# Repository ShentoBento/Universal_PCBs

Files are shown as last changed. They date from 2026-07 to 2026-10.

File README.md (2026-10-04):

# Universal PCBs
note: this was a draft written by AI, its got a ton of errors and is pending manual changes
**Open-source, QMK/VIA-compatible keyboard PCBs designed to fit as many cases as possible.**

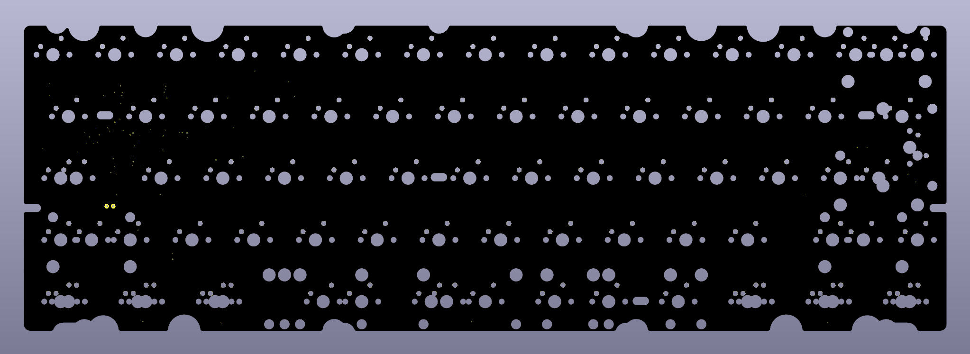
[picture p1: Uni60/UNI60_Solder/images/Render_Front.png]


Most custom keyboard cases are designed around one specific PCB. The boards in this repo work the other way around. Each one is built to drop into as many cases of its form factor as possible, by supporting a wide range of layouts and matching the connector and mounting positions that different cases expect.

---

## Boards

| Board | Form factor | Type | Status | Firmware |
|---|---|---|---|---|
| [**Uni60 Solder**](Uni60/UNI60_Solder) | 60% | Solder | Completed 50 unit GB, Sep 2026 | [Uni60/Solder](https://github.com/ShentoBento/Universal_PCBs_Firmware/tree/main/Uni60/Solder) |
| [**Uni60 Hotswap**](Uni60/UNI60_Hotswap) | 60% | Hotswap | In development | — |

Each board's folder has its own README with full specs, layout diagrams and ordering files.

---

## What "universal" means here

**Layouts.** Each board supports the common layout variations for its size. The Uni60 covers ANSI and ISO, split backspace, split left and right shift, stepped caps, and five bottom rows: 6.25u, 7u, 10u, 2.25u/1.25u/2.75u split, and 3u/1u/3u split.

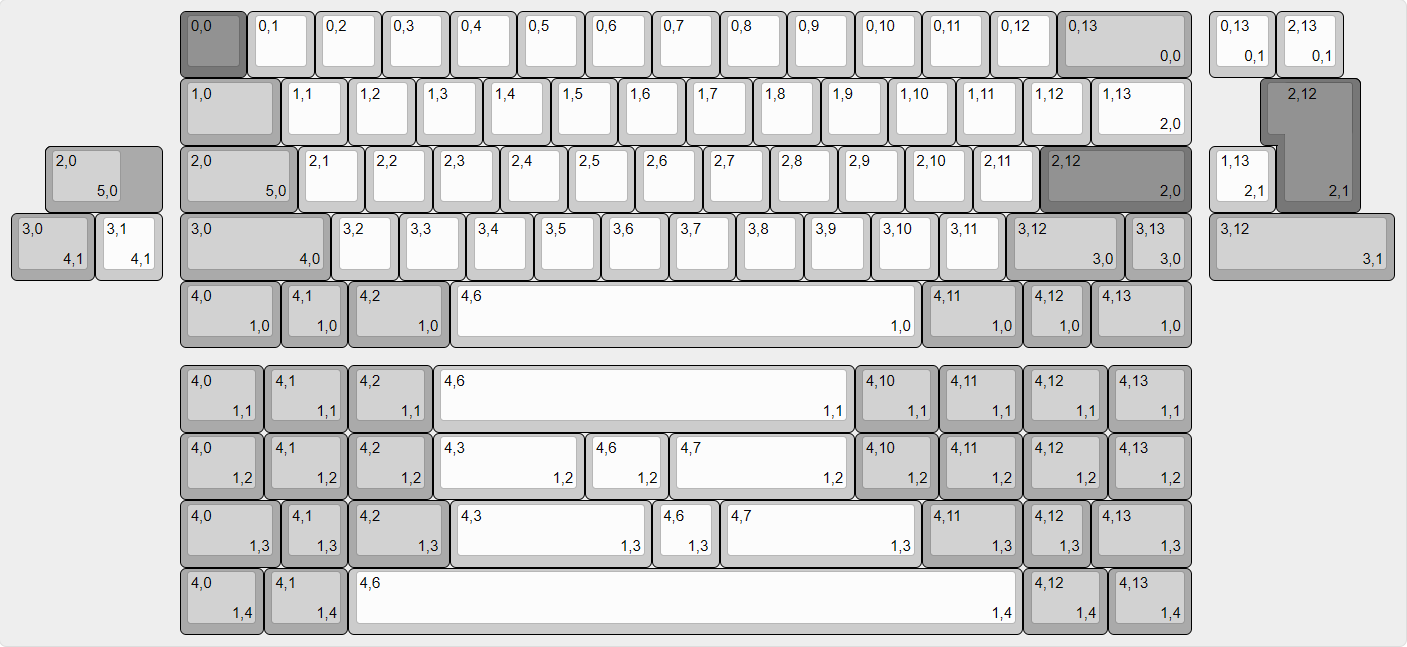
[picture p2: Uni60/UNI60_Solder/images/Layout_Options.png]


**Connectors.** Enthusiast cases route the USB daughterboard cable through a channel, and that channel sits in a different place in nearly every case. A tall JST-SH connector anywhere else bottoms out on the case floor. So the Uni60 has **five daisy-chained JST-SH positions** that line up with common channel locations. Keep the one your case uses and clip or desolder the rest. There's also a **Molex Pico-EZmate** connector, which sits lower than the switch pins and fits any case.

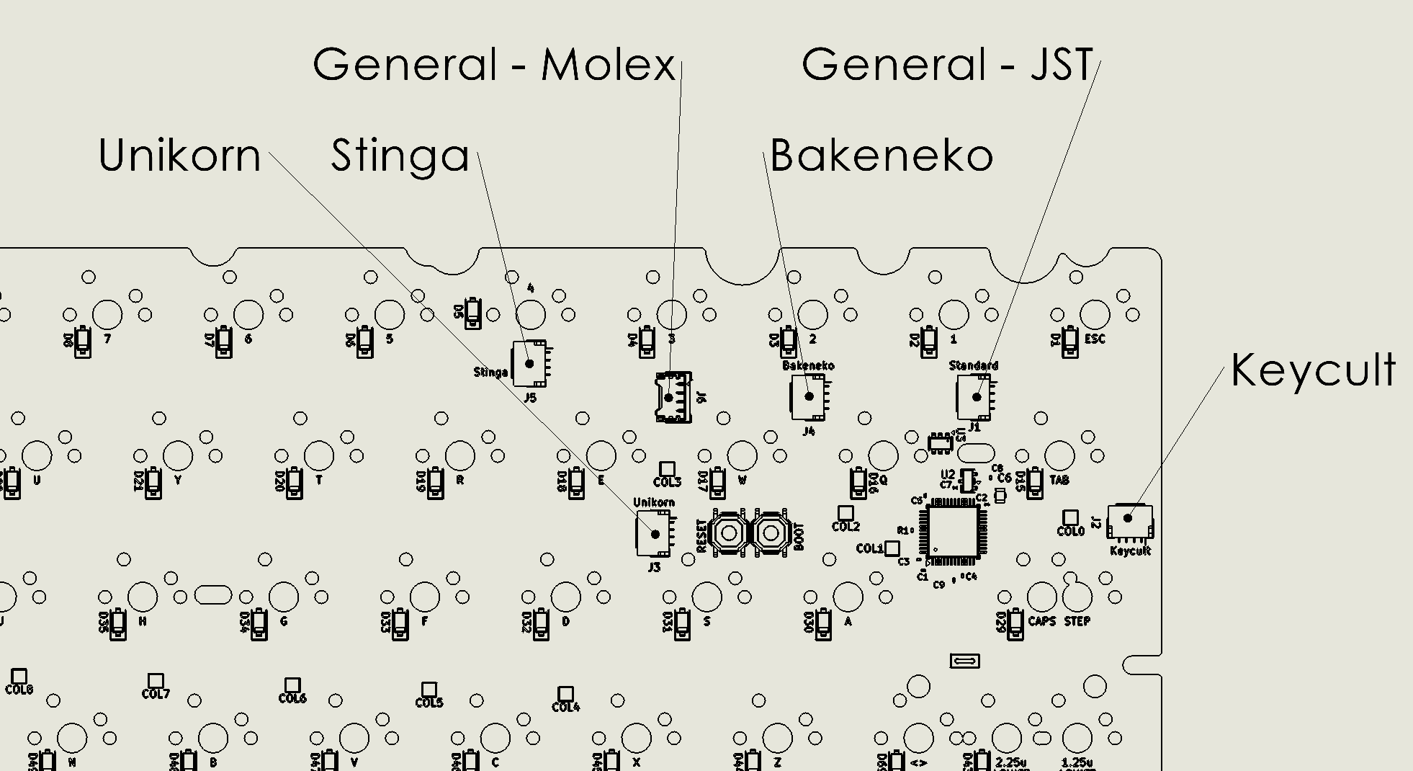
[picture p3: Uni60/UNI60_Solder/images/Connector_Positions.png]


**Outline and mounting.** The board outline is drawn to suit as many cases as possible. It includes tray-mount holes between keys, with the switch matrix routed around them.

---

## Shared specs

- **MCU:** STM32F072CBTx
- **Connectors:** JST-SH 4-pin (multiple positions) and Molex Pico-EZmate 4-pin
- **Firmware:** QMK with VIA and Vial support, in [Universal_PCBs_Firmware](https://github.com/ShentoBento/Universal_PCBs_Firmware)
- **Design tool:** KiCad 10 or newer (earlier versions won't open the files)
- **Manufacturing:** fab and assembly files generated for JLCPCB

---

## Repository layout

```
Universal_PCBs/
├── Uni60/
│   ├── UNI60_Solder/              complete: KiCad project, production files, images
│   └── UNI60_Hotswap/             in development
└── shentobento_kicad_library/     shared symbols, footprints and 3D models
```

## Using these files

1. Clone or download the **whole repo**, not just one board's folder. Every board points at the shared `shentobento_kicad_library/` with relative paths, so the projects open on any machine with no library setup.
2. Open the board's `.kicad_pro` file in KiCad 10 or newer.
3. To order boards, use the files in that board's `production/` folder (gerbers, BOM, positions). If you change the design, regenerate them with the JLCPCB Fabrication Toolkit plugin.

## Related

- [Universal_PCBs_Firmware](https://github.com/ShentoBento/Universal_PCBs_Firmware): QMK firmware for these boards
- [Velvet-Pro-Solder-PCB](https://github.com/ShentoBento/Velvet-Pro-Solder-PCB): the board whose matrix and MCU design the Uni60 builds on

## Credits and licenses

Keyboard footprints and symbols are derived from [marbastlib](https://github.com/ebastler/marbastlib) by ebastler, licensed under CERN-OHL-P v2. See `shentobento_kicad_library/LICENSE-marbastlib.txt`; modifications are logged in `shentobento_kicad_library/NOTICE.md`. Generic footprints come from the KiCad standard libraries.

---

Designed by **Andrew Shentu** ([@ShentoBento](https://github.com/ShentoBento)) · [LinkedIn](https://www.linkedin.com/in/andrewshentu)

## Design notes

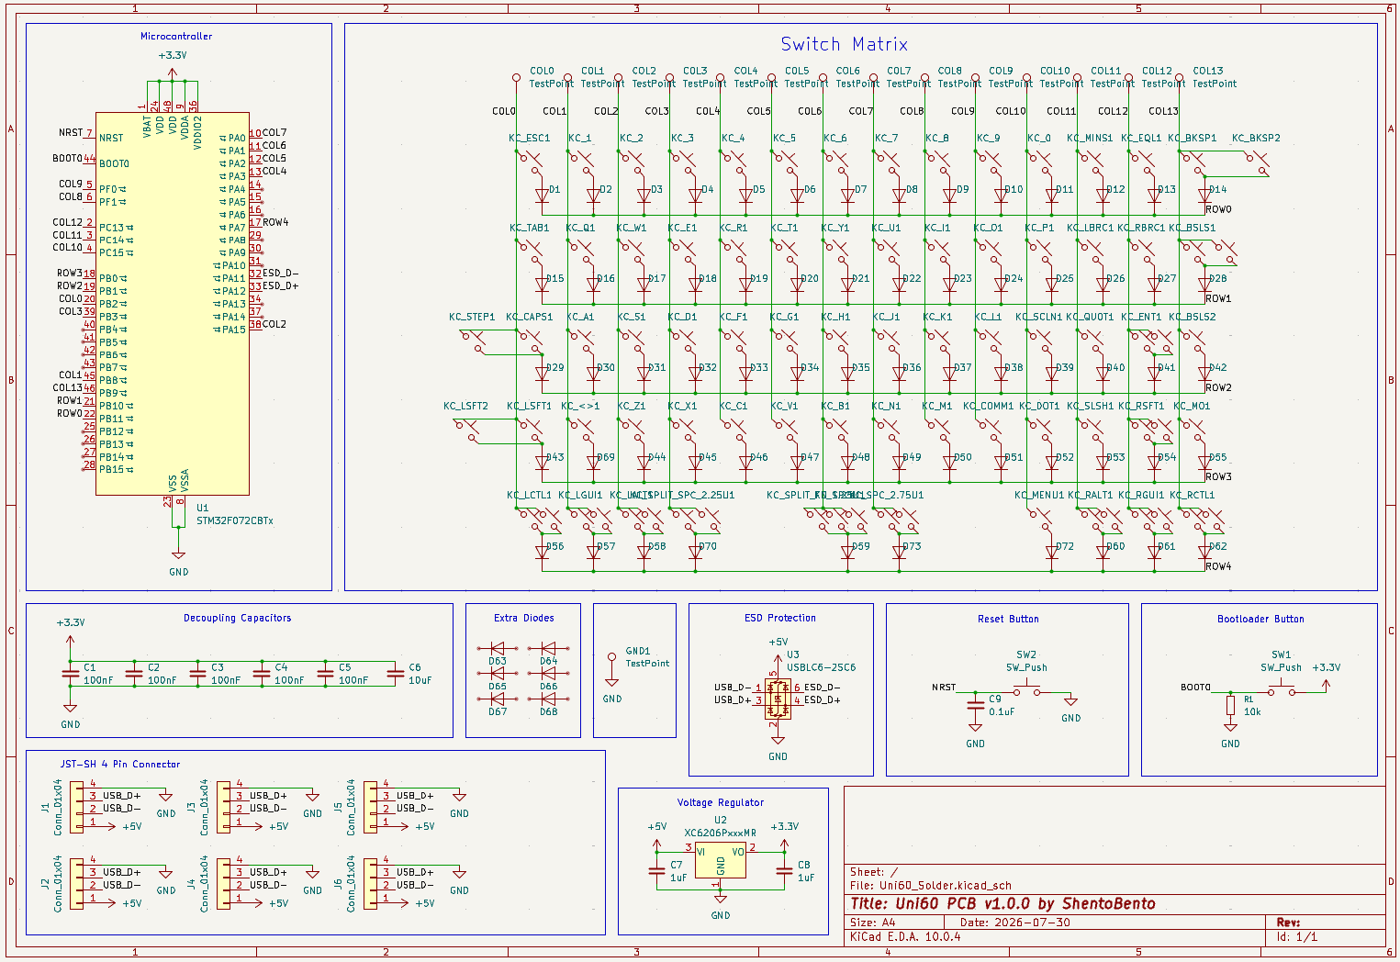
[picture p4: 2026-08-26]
Uni60/UNI60_Solder/images/Kicad_Schematic.png

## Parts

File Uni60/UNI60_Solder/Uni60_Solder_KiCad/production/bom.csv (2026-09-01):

Designator | Footprint | Quantity | Value | LCSC Part #
C1, C2, C3, C4, C5 | 0201 | 5 | 100nF
C6 | 0805 | 1 | 10uF
C7, C8 | 0201 | 2 | 1uF
C9 | 0201 | 1 | 0.1uF
COL0, COL1, COL10, COL11, COL12, COL13, COL2, COL3, COL4, COL5, COL6, COL7, COL8, COL9 | TestPoint_Pad_1.5x1.5mm | 14 | TestPoint
D1, D10, D11, D12, D13, D14, D15, D16, D17, D18, D19, D2, D20, D21, D22, D23, D24, D25, D26, D27, D28, D29, D3, D30, D31, D32, D33, D34, D35, D36, D37, D38, D39, D4, D40, D41, D42, D43, D44, D45, D46, D47, D48, D49, D5, D50, D51, D52, D53, D54, D55, D56, D57, D58, D59, D6, D60, D61, D62, D63, D64, D65, D66, D67, D68, D69, D7, D70, D72, D73, D8, D9 | D_SOD-123 | 72 | 1N4148
GND1 | TestPoint_Bridge_Pitch2.0mm_Drill0.7mm | 1 | TestPoint
J1, J2, J3, J4, J5 | JST_SH_1x04 | 5 | Conn_01x04
J6 | Molex_Pico-EZmate_78171-0004_1x04-1MP_P1.20mm_Vertical | 1 | Conn_01x04
KC_0, KC_1, KC_2, KC_3, KC_4, KC_5, KC_6, KC_7, KC_8, KC_9, KC_<>1, KC_A1, KC_B1, KC_BKSP1, KC_BKSP2, KC_BSLS2, KC_BSLS_ISO1, KC_C1, KC_COMM1, KC_D1, KC_DOT1, KC_E1, KC_ENT1, KC_ENT_ISO1, KC_EQL1, KC_ESC1, KC_F1, KC_G1, KC_H1, KC_I1, KC_J1, KC_K1, KC_L1, KC_LBRC1, KC_LGUI1, KC_LSFT1, KC_M1, KC_MINS1, KC_MO1, KC_N1, KC_O1, KC_P1, KC_Q1, KC_QUOT1, KC_R1, KC_RBRC1, KC_RGUI1, KC_RSFT1, KC_RSFT_2.75U1, KC_S1, KC_SCLN1, KC_SLSH1, KC_SPC1, KC_SPC_2.75U1, KC_SPC_3U1, KC_SPC_6.25U1, KC_SPLIT_SPC_2.25U1, KC_SPLIT_SPC_3U1, KC_T1, KC_U1, KC_V1, KC_W1, KC_X1, KC_Y1, KC_Z1 | SW_MX_1u | 65 | MX_SW_solder
KC_BSLS1, KC_LALT1, KC_LCTL1, KC_RALT1, KC_RCTL1, KC_TAB1 | SW_MX_1.5u | 6 | MX_SW_solder
KC_CAPS1 | SW_MX_1.75u | 1 | MX_SW_solder
KC_LALT_1.25U1, KC_LCTL_1.25U1, KC_LGUI_1.25U1, KC_LSFT2, KC_MENU1, KC_RALT_1.25U1, KC_RCTL_1.25U1, KC_RGUI_1.25U1, KC_SPLIT_FN_1.25U1 | SW_MX_1.25u | 9 | MX_SW_solder
KC_STEP1 | SW_MX_1.75u_STEPPED_1.25 | 1 | MX_SW_solder
R1 | 0201 | 1 | 10k
SW1, SW2 | SW_Push_Reset_Bootloader | 2 | SW_Push
U1 | MCU_STM32F072CBTx | 1 | STM32F072CBTx
U2 | SOT-23-3 | 1 | XC6206PxxxMR
U3 | SOT-23-6 | 1 | USBLC6-2SC6

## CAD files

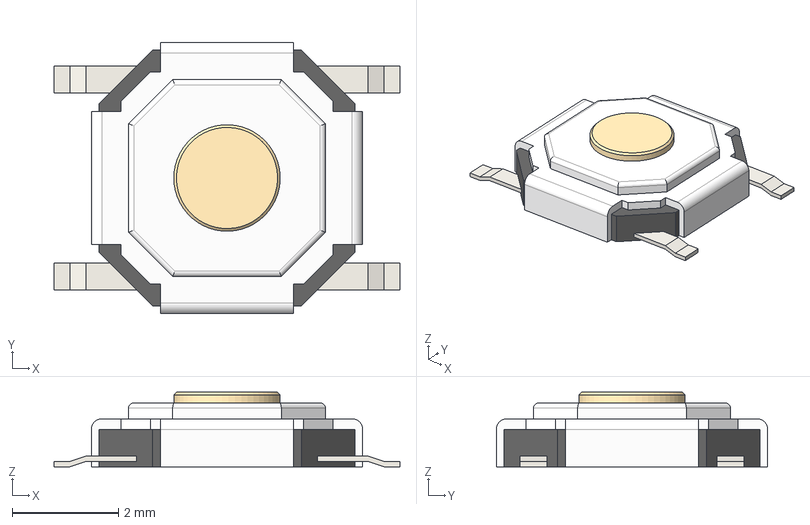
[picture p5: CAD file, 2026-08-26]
shentobento_kicad_library/3dmodels/TS-1187A.step
6.50 x 5.10 x 1.40 mm

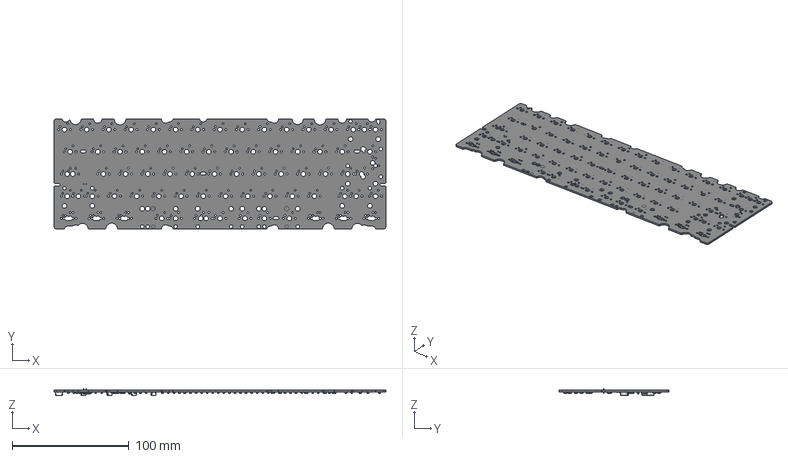
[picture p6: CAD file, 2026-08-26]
Uni60/UNI60_Solder/files/UNI60_PCB.step
284.7 x 94.2 x 5.96 mm
D_SOD-123 x 72
C_0201_0603Metric x 8
CON_781710004 v2
R_0201_0603Metric
TS-1187A v2 x 2
JST_SH_SM04B-SRSS-TB_1x04-1MP_P1.00mm_Horizontal x 5
SOT-23-6
LQFP-48_7x7mm_P0.5mm
TestPoint_Bridge_Pitch2.0mm_Drill0.7mm
C_0805_2012Metric
SOT-23-3
Uni60_Solder_silkscreen
Uni60_Solder_PCB

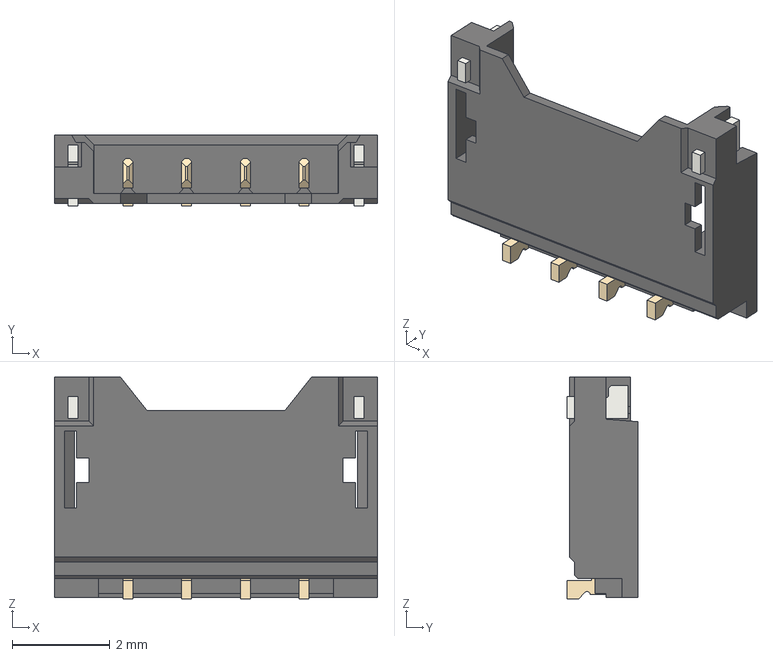
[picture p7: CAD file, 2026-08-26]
shentobento_kicad_library/3dmodels/CON_781710004.step
6.60 x 1.45 x 4.53 mm

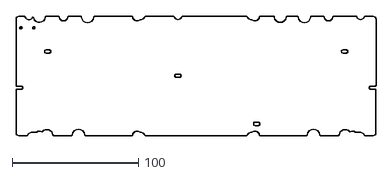
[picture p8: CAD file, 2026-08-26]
Uni60/UNI60_Solder/files/Uni60_PCB_Outline.dxf
284.7 x 94.2

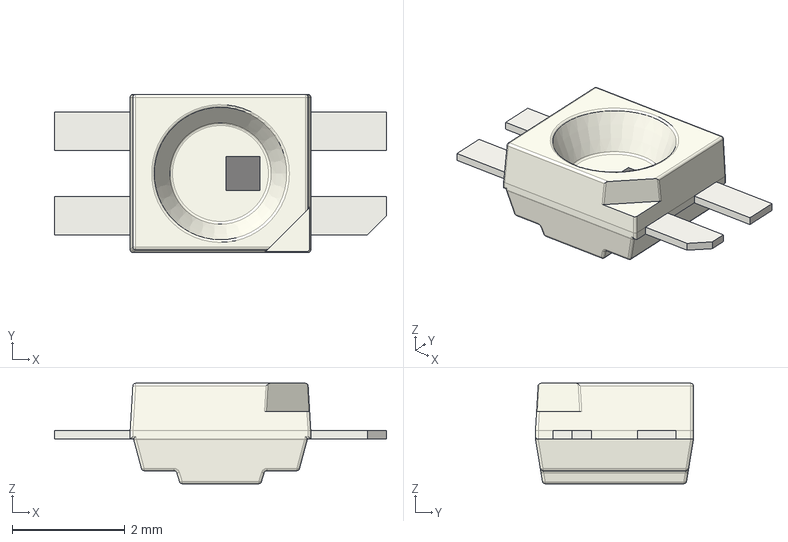
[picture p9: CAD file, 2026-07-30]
shentobento_kicad_library/3dmodels/LED_SK6812MINI-E.step
5.88 x 2.80 x 1.78 mm

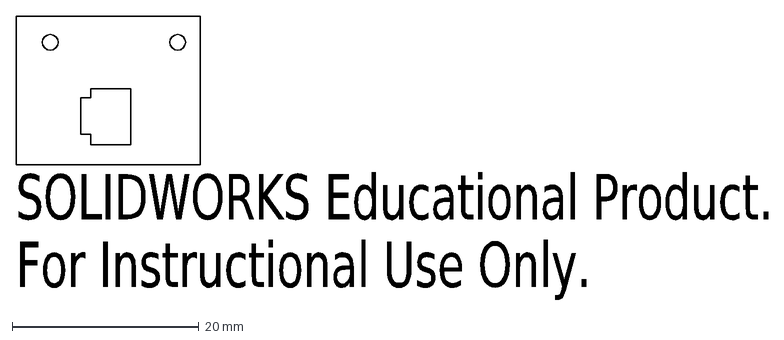
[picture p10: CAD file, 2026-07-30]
Uni60/UNI60_Solder/files/JST Position.DXF
SOLIDWORKS Educational Product.
For Instructional Use Only.

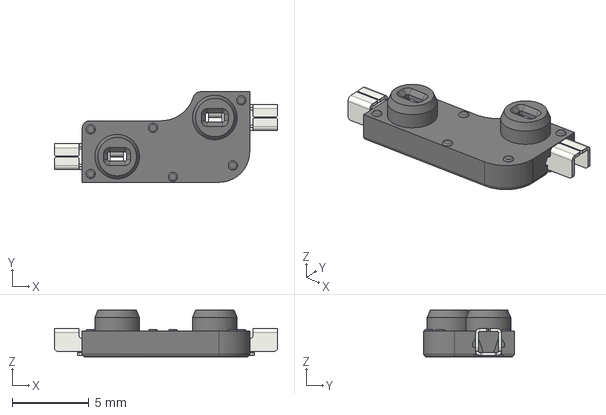
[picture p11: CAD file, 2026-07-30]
shentobento_kicad_library/3dmodels/HS_CPG151101S11_MX.step
14.5 x 5.89 x 3.05 mm
Contact x 2

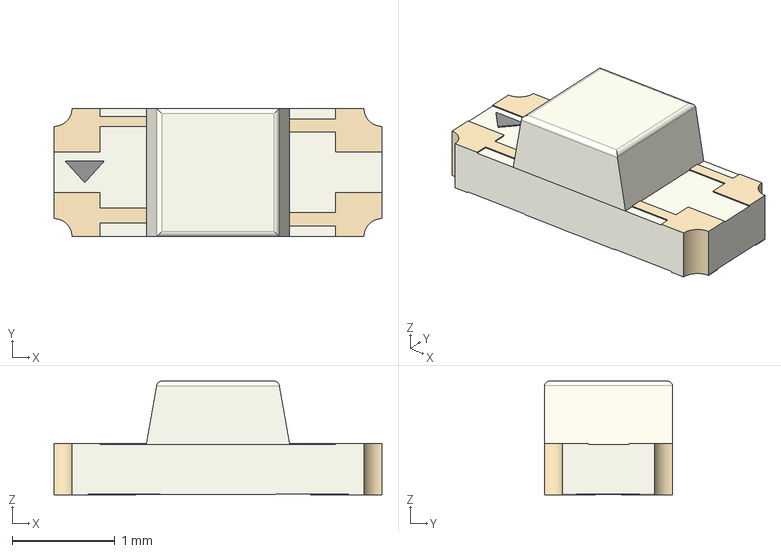
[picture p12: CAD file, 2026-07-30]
shentobento_kicad_library/3dmodels/LED_MHT151RGBCT.step
3.20 x 1.25 x 1.11 mm

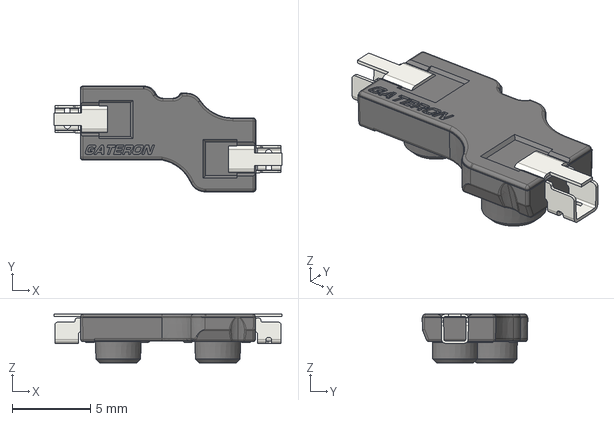
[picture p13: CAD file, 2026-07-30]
shentobento_kicad_library/3dmodels/HS_KS-2P02B01-01_MX.step
14.6 x 6.74 x 3.10 mm

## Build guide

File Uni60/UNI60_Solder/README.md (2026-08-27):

# Uni60 Solder PCB



A solder PCB designed to fit most JST-dependent 60% Keyboards.

Firmware: https://github.com/ShentoBento/Universal_PCBs_Firmware/tree/main/Uni60/Solder

---

## Specs



- Solder
- MCU: STM32F072CBTx
- 5 JST SH connector positions
- 1.55mm socket diameters (compatible with millmax)
- 1 molex pico ezmate connector
- ISO support
- Split backspace
- Split right shift
- Split left shift
- Stepped/full caps
- 7u/6.25u bottom row
- 2.25/1.25u/2.75u split spacebar
- 3u/1u/3u split spacebar
- 10u spacebar
- VIA and Vial compatible (via the firmware linked above)



---

## Requirements

- **KiCad 10** or newer. Earlier versions will not open these files.
- Nothing else. All symbols, footprints, and 3D models used by this project are
  included in this repo — no external libraries to install, no PCM packages,
  no library paths to configure.

---

## Opening the project

1. Clone or download this whole repo (not just the specific pcb folder).
2. Open `Uni60_Solder_KiCad/Uni60_Solder.KiCad_pro` in KiCad.

The library paths are stored relative to the project folder, so the repo works
from any location on any operating system. If KiCad reports missing symbols or
footprints, the most likely cause is that the `shentobento_kicad_library/`
folder was not cloned alongside.

---

## What's in this repo

### `Uni60_Solder_KiCad/`

The KiCad project. These are the files you edit.

| File | What it is |
|---|---|
| `Uni60_Solder.kicad_pro` | Project file — **open this one** |
| `Uni60_Solder.kicad_sch` | Schematic |
| `Uni60_Solder.kicad_pcb` | Board layout |
| `fp-lib-table`, `sym-lib-table` | Point KiCad at the bundled library |
| `fabrication-toolkit-options.json` | Settings for the JLCPCB fabrication plugin |

### `Uni60_Solder_KiCad/production/`

Ready-to-order manufacturing files, generated with the JLCPCB Fabrication Toolkit plugin.

| File | Upload it to |
|---|---|
| `Uni60_Solder.zip` | JLCPCB's gerber upload — this is the board itself |
| `bom.csv` | Assembly service (which parts) |
| `positions.csv` | Assembly service (where they go) |

If you modify the design, **regenerate these** with the JLCPCB Fabrication Toolkit plugin.

### `shentobento_kicad_library/`

Every symbol and footprint this project uses, in one place.

- `shentobento.kicad_sym` — all symbols
- `shentobento.pretty/` — all footprints
- `3dmodels/` — 3D models for the parts that need them

Symbols come with their footprints pre-assigned, so dragging a part into a
schematic gives you a working part with no footprint assignment step.

This folder is self-contained and can be copied into other keyboard projects.

### `files and images`

- `Uni60_PCB_Outline.dxf` — outline used for the pcb
- `JST Position.dxf` — the General-JST connector position

---

## Credits and licenses

Keyboard footprints and symbols are derived from
[marbastlib](https://github.com/ebastler/marbastlib) by ebastler, licensed under
CERN-OHL-P v2. See `shentobento_kicad_library/LICENSE-marbastlib.txt`.

Generic footprints (passives, SOT-23, LQFP-48, JST SH, test points) are copied
from the KiCad standard libraries.

Modifications made to third-party files are recorded in
`shentobento_kicad_library/NOTICE.md`.

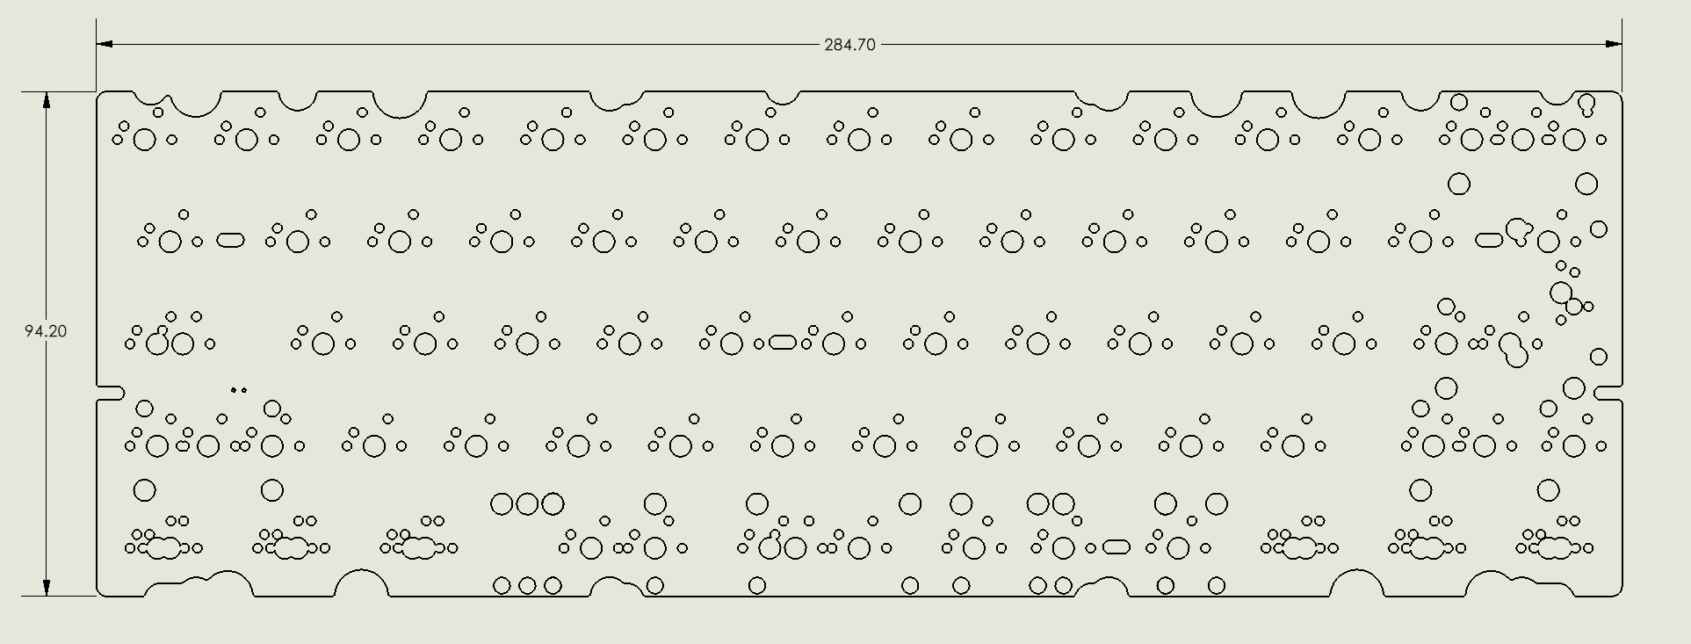
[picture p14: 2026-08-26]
Uni60/UNI60_Solder/images/Dimensions.png

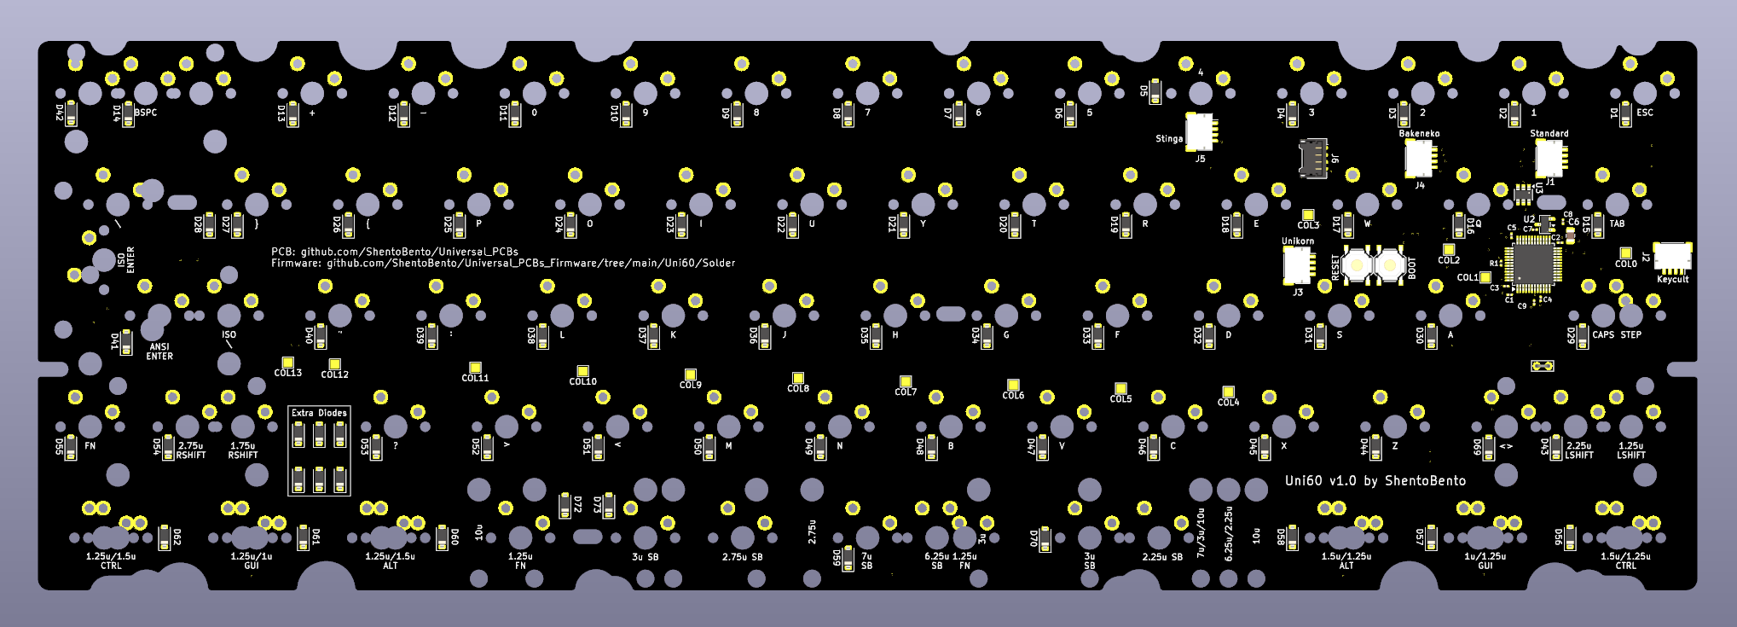
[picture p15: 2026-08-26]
Uni60/UNI60_Solder/images/Render_Back.png

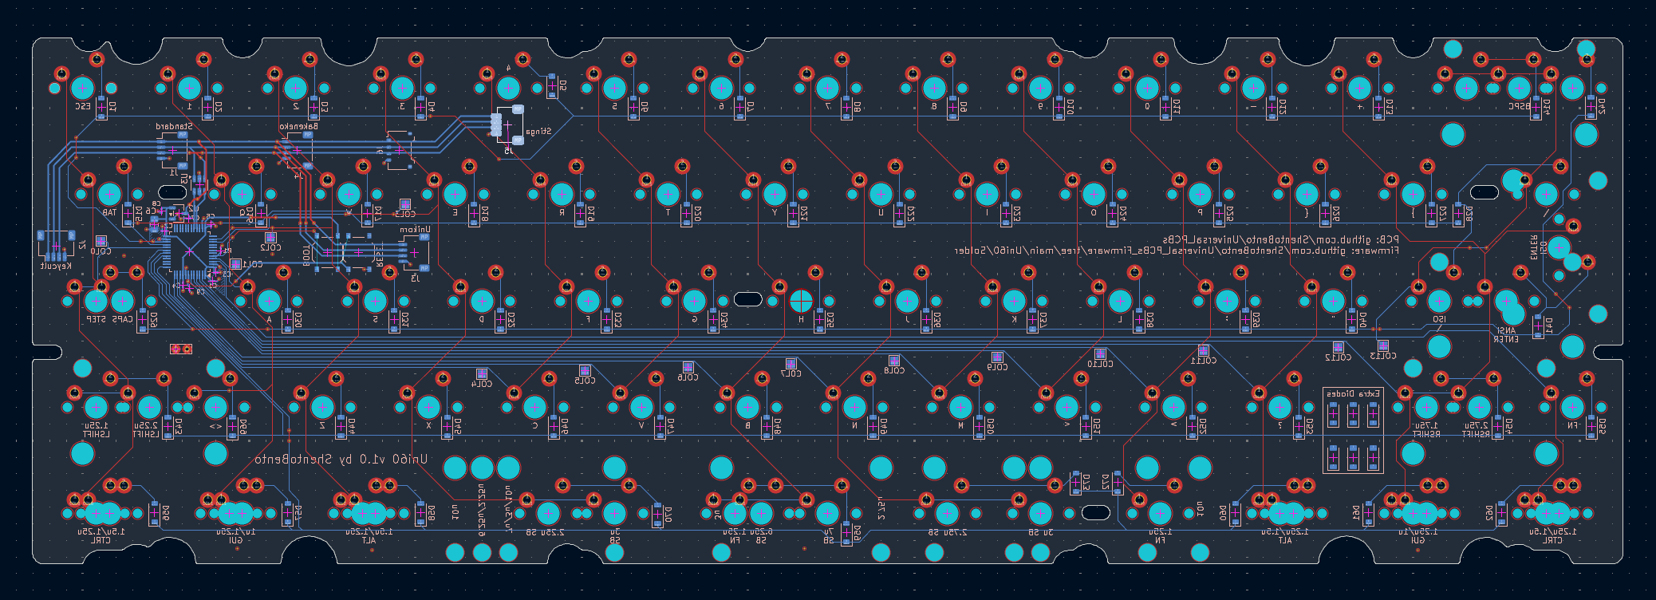
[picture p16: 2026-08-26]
Uni60/UNI60_Solder/images/Kicad_PCB.png

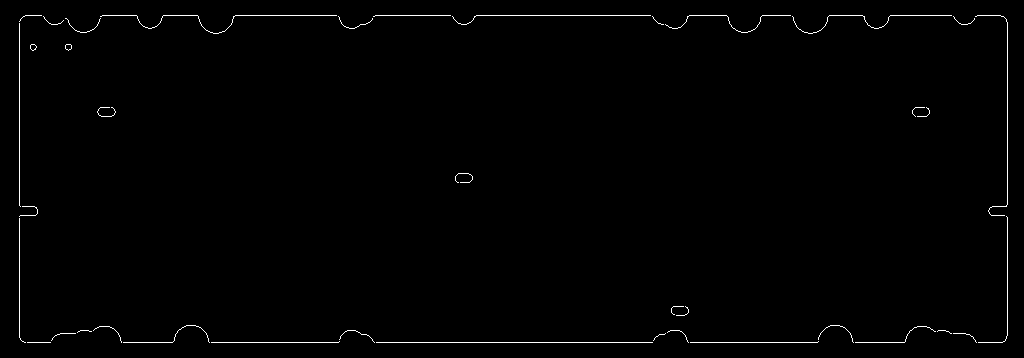
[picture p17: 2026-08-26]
Uni60/UNI60_Solder/files/Uni60_PCB_Outline.png

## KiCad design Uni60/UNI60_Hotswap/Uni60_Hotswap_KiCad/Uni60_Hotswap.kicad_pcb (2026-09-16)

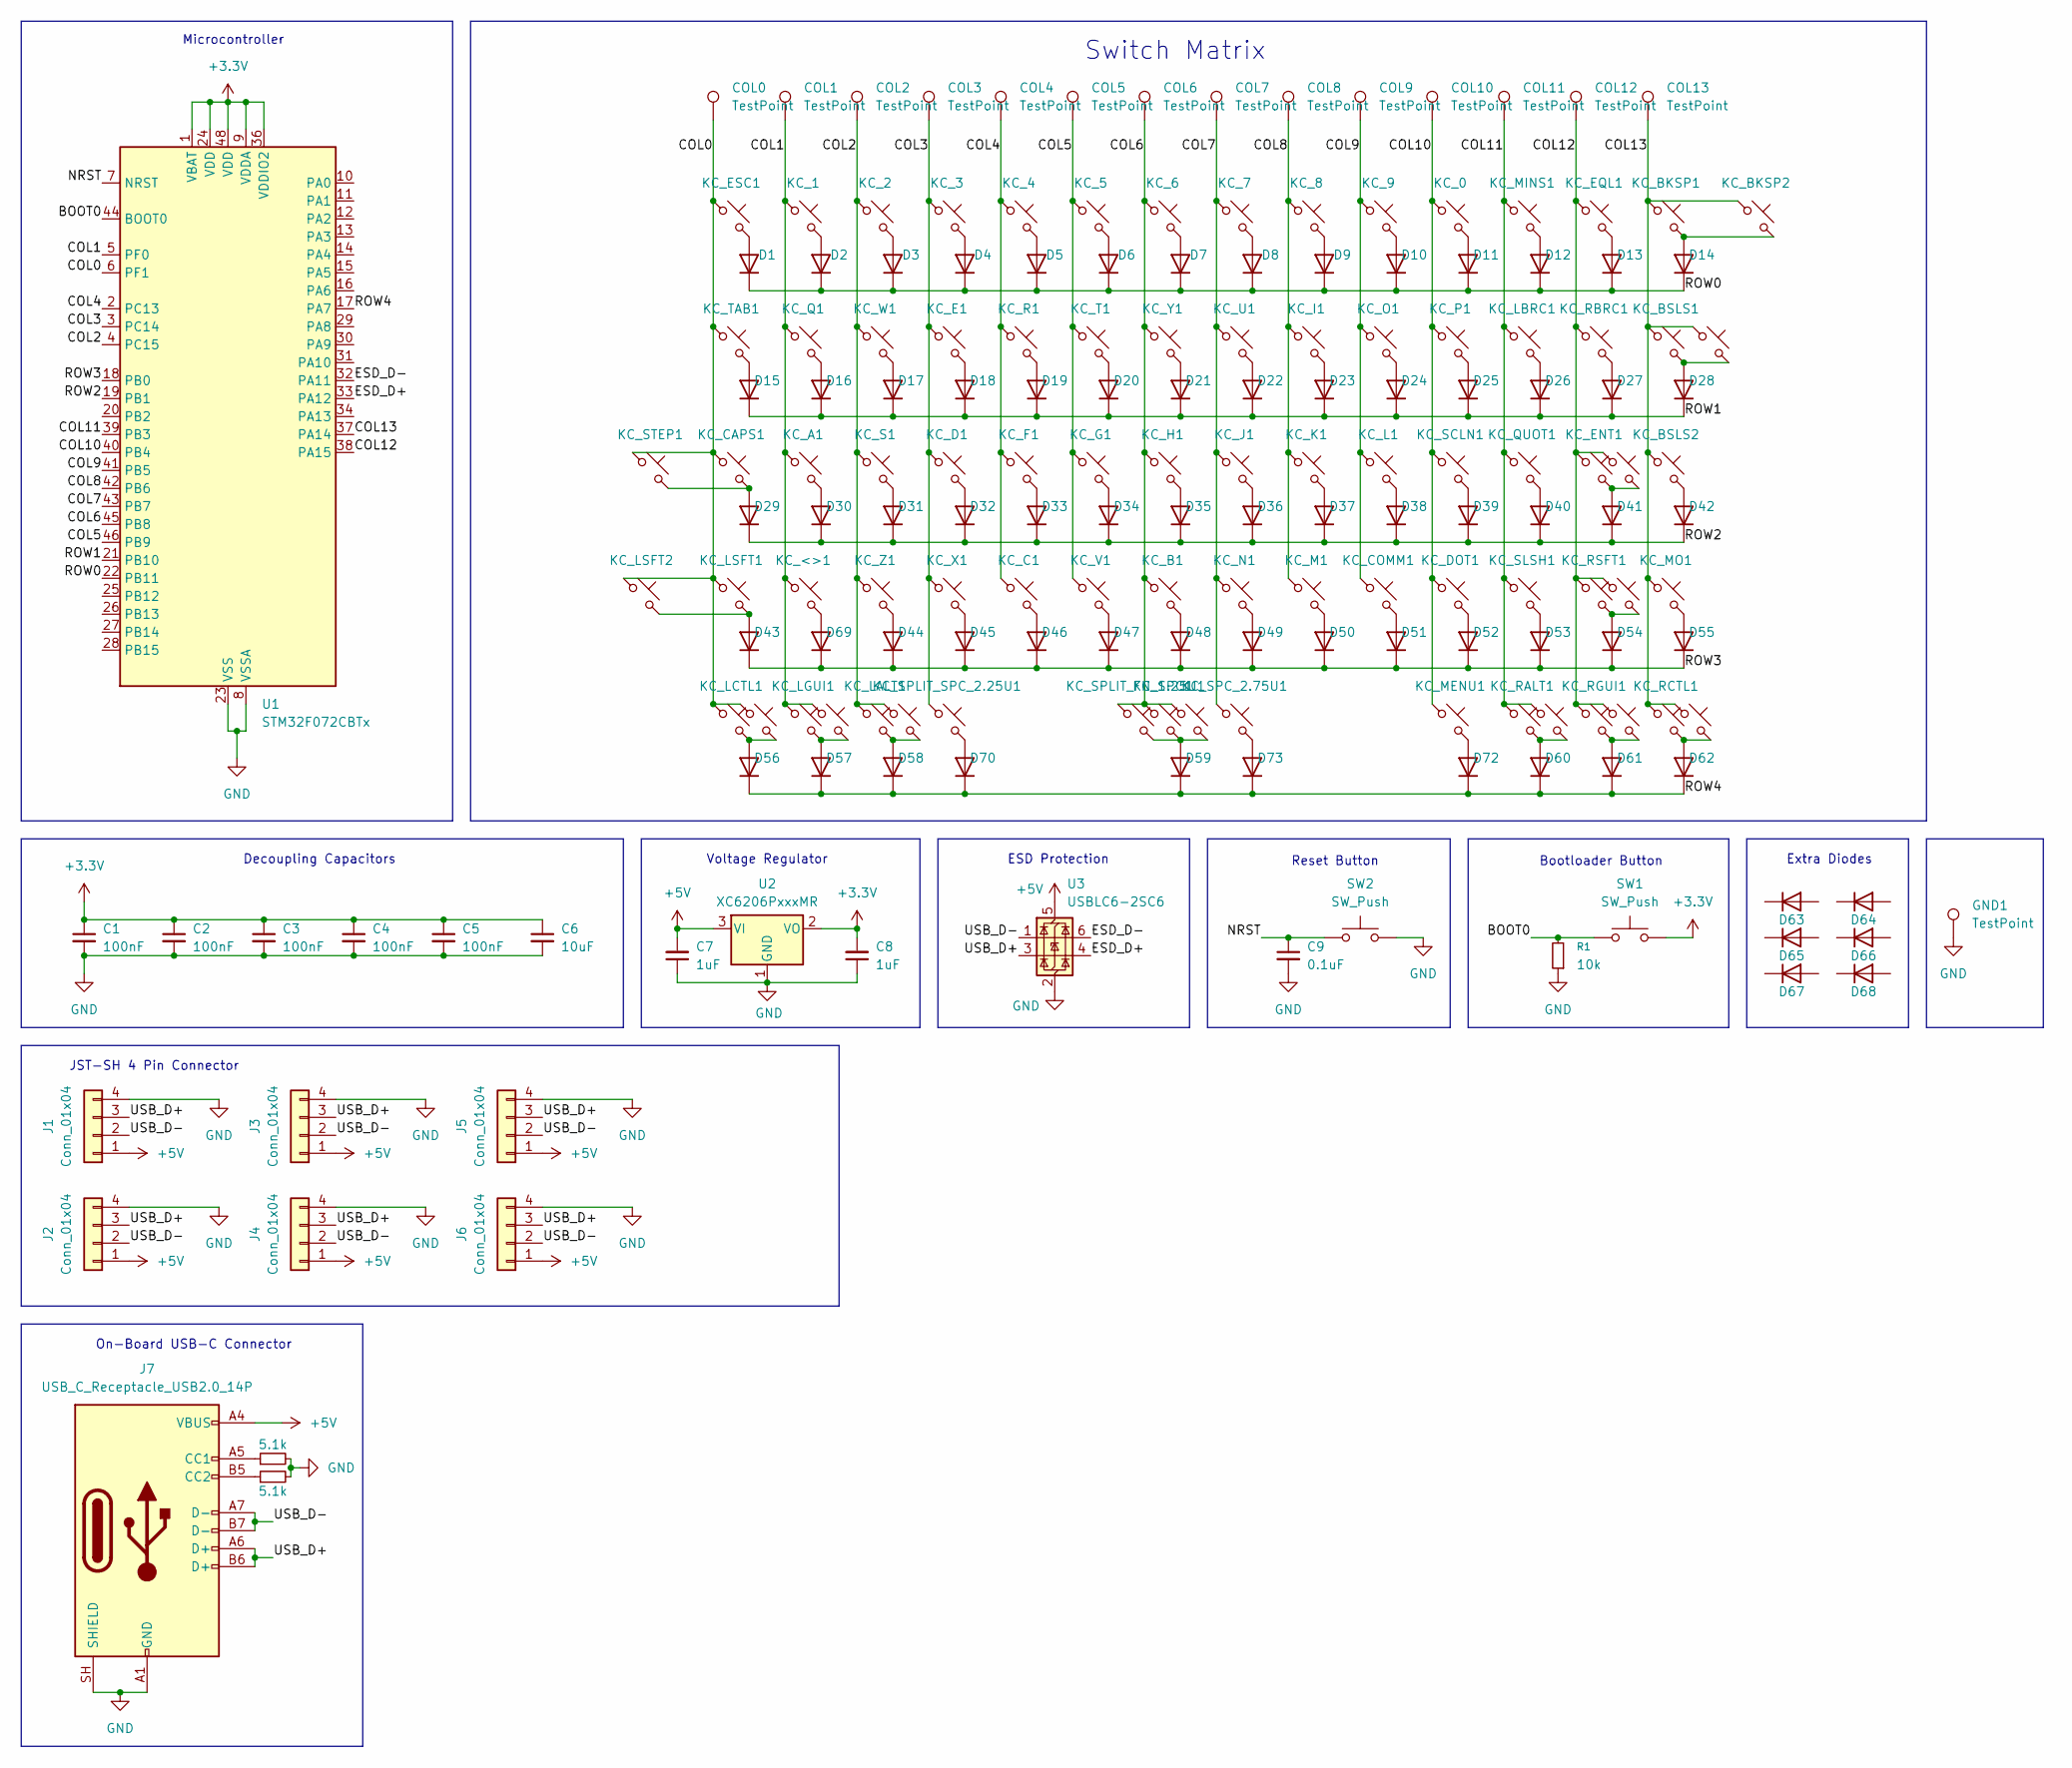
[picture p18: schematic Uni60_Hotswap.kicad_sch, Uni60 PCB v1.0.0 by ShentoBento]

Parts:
C1, C2, C3, C4, C5: 100nF; C_0201_0603Metric
C6: 10uF; C_0805_2012Metric
C7, C8: 1uF; C_0201_0603Metric
C9: 0.1uF; C_0201_0603Metric
COL0, COL1, COL2, COL3, COL4, COL5, COL6, COL7, COL8, COL9, COL10, COL11, COL12, COL13: TestPoint; TestPoint_Pad_1.5x1.5mm
D1, D2, D3, D4, D5, D6, D7, D8, D9, D10, D11, D12, D13, D14, D15, D16, D17, D18, D19, D20, D21, D22, D23, D24, D25, D26, D27, D28, D29, D30, D31, D32, D33, D34, D35, D36, D37, D38, D39, D40, D41, D42, D43, D44, D45, D46, D47, D48, D49, D50, D51, D52, D53, D54, D55, D56, D57, D58, D59, D60, D61, D62, D63, D64, D65, D66, D67, D68, D69, D70, D72, D73: 1N4148; D_SOD-323
GND1: TestPoint; TestPoint_Bridge_Pitch2.0mm_Drill0.7mm
J1, J2, J3, J4, J5: Conn_01x04; JST_SH_1x04
J6: Conn_01x04; Molex_Pico-EZmate_78171-0004_1x04-1MP_P1.20mm_Vertical
J7: USB_C_Receptacle_USB2.0_14P; USB_C_Receptacle_GCT_USB4105-xx-A_16P_TopMnt_Horizontal
KC_0, KC_1, KC_2, KC_3, KC_4, KC_5, KC_6, KC_7, KC_8, KC_9: MX_SW_solder; SW_MX_HS_KAILH_1u
KC_<>1: MX_SW_solder; SW_MX_HS_KAILH_1u
KC_A1: MX_SW_solder; SW_MX_HS_KAILH_1u
KC_B1: MX_SW_solder; SW_MX_HS_KAILH_1u
KC_BKSP1, KC_BKSP2: MX_SW_solder; SW_MX_HS_KAILH_1u
KC_BSLS1: MX_SW_solder; SW_MX_HS_KAILH_1.5u
KC_BSLS2: MX_SW_solder; SW_MX_HS_KAILH_1u
KC_BSLS_ISO1: MX_SW_solder; SW_MX_HS_KAILH_1u
KC_C1: MX_SW_solder; SW_MX_HS_KAILH_1u
KC_CAPS1: MX_SW_solder; SW_MX_HS_KAILH_1.75u
KC_COMM1: MX_SW_solder; SW_MX_HS_KAILH_1u
KC_D1: MX_SW_solder; SW_MX_HS_KAILH_1u
KC_DOT1: MX_SW_solder; SW_MX_HS_KAILH_1u
KC_E1: MX_SW_solder; SW_MX_HS_KAILH_1u
KC_ENT1: MX_SW_solder; SW_MX_HS_KAILH_1u
KC_ENT_ISO1: MX_SW_solder; SW_MX_HS_KAILH_1u
KC_EQL1: MX_SW_solder; SW_MX_HS_KAILH_1u
KC_ESC1: MX_SW_solder; SW_MX_HS_KAILH_1u
KC_F1: MX_SW_solder; SW_MX_HS_KAILH_1u
KC_G1: MX_SW_solder; SW_MX_HS_KAILH_1u
KC_H1: MX_SW_solder; SW_MX_HS_KAILH_1u
KC_I1: MX_SW_solder; SW_MX_HS_KAILH_1u
KC_J1: MX_SW_solder; SW_MX_HS_KAILH_1u
KC_K1: MX_SW_solder; SW_MX_HS_KAILH_1u
KC_L1: MX_SW_solder; SW_MX_HS_KAILH_1u
KC_LALT1: MX_SW_solder; SW_MX_HS_KAILH_1.5u
KC_LALT_1.25U1: MX_SW_solder; SW_MX_HS_KAILH_1.25u
KC_LBRC1: MX_SW_solder; SW_MX_HS_KAILH_1u
KC_LCTL1: MX_SW_solder; SW_MX_HS_KAILH_1.5u
KC_LCTL_1.25U1: MX_SW_solder; SW_MX_HS_KAILH_1.25u
KC_LGUI1: MX_SW_solder; SW_MX_HS_KAILH_1u
KC_LGUI_1.25U1: MX_SW_solder; SW_MX_HS_KAILH_1.25u
KC_LSFT1: MX_SW_solder; SW_MX_HS_KAILH_1u
KC_LSFT2: MX_SW_solder; SW_MX_HS_KAILH_1.25u
KC_M1: MX_SW_solder; SW_MX_HS_KAILH_1u
KC_MENU1: MX_SW_solder; SW_MX_HS_KAILH_1.25u
KC_MINS1: MX_SW_solder; SW_MX_HS_KAILH_1u
KC_MO1: MX_SW_solder; SW_MX_HS_KAILH_1u
KC_N1: MX_SW_solder; SW_MX_HS_KAILH_1u
KC_O1: MX_SW_solder; SW_MX_HS_KAILH_1u
KC_P1: MX_SW_solder; SW_MX_HS_KAILH_1u
KC_Q1: MX_SW_solder; SW_MX_HS_KAILH_1u
KC_QUOT1: MX_SW_solder; SW_MX_HS_KAILH_1u
KC_R1: MX_SW_solder; SW_MX_HS_KAILH_1u
KC_RALT1: MX_SW_solder; SW_MX_HS_KAILH_1.5u
KC_RALT_1.25U1: MX_SW_solder; SW_MX_HS_KAILH_1.25u
KC_RBRC1: MX_SW_solder; SW_MX_HS_KAILH_1u
KC_RCTL1: MX_SW_solder; SW_MX_HS_KAILH_1.5u
KC_RCTL_1.25U1: MX_SW_solder; SW_MX_HS_KAILH_1.25u
KC_RGUI1: MX_SW_solder; SW_MX_HS_KAILH_1u
KC_RGUI_1.25U1: MX_SW_solder; SW_MX_HS_KAILH_1.25u
KC_RSFT1: MX_SW_solder; SW_MX_HS_KAILH_1u
KC_RSFT_2.75u1: MX_SW_solder; SW_MX_HS_KAILH_1u
KC_S1: MX_SW_solder; SW_MX_HS_KAILH_1u
KC_SCLN1: MX_SW_solder; SW_MX_HS_KAILH_1u
KC_SLSH1: MX_SW_solder; SW_MX_HS_KAILH_1u
KC_SPC1: MX_SW_solder; SW_MX_HS_KAILH_1u
KC_SPC_2.75U1, KC_SPC_6.25U1: MX_SW_solder; SW_MX_HS_KAILH_1u
KC_SPLIT_FN_1.25U1: MX_SW_solder; SW_MX_HS_KAILH_1.25u
KC_SPLIT_SPC_2.25U1: MX_SW_solder; SW_MX_HS_KAILH_1u
KC_STEP1: MX_SW_solder; SW_MX_HS_KAILH_1.75u_STEPPED_1.25
KC_T1: MX_SW_solder; SW_MX_HS_KAILH_1u
KC_TAB1: MX_SW_solder; SW_MX_HS_KAILH_1.5u
KC_U1: MX_SW_solder; SW_MX_HS_KAILH_1u
KC_V1: MX_SW_solder; SW_MX_HS_KAILH_1u
KC_W1: MX_SW_solder; SW_MX_HS_KAILH_1u
KC_X1: MX_SW_solder; SW_MX_HS_KAILH_1u
KC_Y1: MX_SW_solder; SW_MX_HS_KAILH_1u
KC_Z1: MX_SW_solder; SW_MX_HS_KAILH_1u
R1: 10k; R_0201_0603Metric
R2, R3: 5.1k; R_0201_0603Metric
SW1, SW2: SW_Push; SW_Push_Reset_Bootloader
U1: STM32F072CBTx; MCU_STM32F072CBTx
U2: XC6206PxxxMR; SOT-23-3
U3: USBLC6-2SC6; SOT-23-6

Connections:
+3.3V: C1.1, C2.1, C3.1, C4.1, C5.1, C6.1, C8.2, SW1.2, U1.1 (VBAT), U1.9 (VDDA), U1.24 (VDD), U1.36 (VDDIO2), U1.48 (VDD), U2.2 (VO)
+5V: C7.2, J1.1, J2.1, J3.1, J4.1, J5.1, J6.1, J7.A4 (VBUS), J7.A9 (VBUS), J7.B4 (VBUS), J7.B9 (VBUS), U2.3 (VI), U3.5 (VBUS)
/BOOT0: R1.2, SW1.1, U1.44 (BOOT0)
/COL0: COL0.1 (1_1), KC_CAPS1.1, KC_ESC1.1, KC_LCTL1.1, KC_LCTL_1.25U1.1, KC_LSFT1.1, KC_LSFT2.1, KC_STEP1.1, KC_TAB1.1, U1.6 (PF1)
/COL1: COL1.1 (1_1), KC_1.1, KC_<>1.1, KC_A1.1, KC_LGUI1.1, KC_LGUI_1.25U1.1, KC_Q1.1, U1.5 (PF0)
/COL2: COL2.1 (1_1), KC_2.1, KC_LALT1.1, KC_LALT_1.25U1.1, KC_S1.1, KC_W1.1, KC_Z1.1, U1.4 (PC15)
/COL3: COL3.1 (1_1), KC_3.1, KC_D1.1, KC_E1.1, KC_SPLIT_SPC_2.25U1.1, KC_X1.1, U1.3 (PC14)
/COL4: COL4.1 (1_1), KC_4.1, KC_C1.1, KC_F1.1, KC_R1.1, U1.2 (PC13)
/COL5: COL5.1 (1_1), KC_5.1, KC_G1.1, KC_T1.1, KC_V1.1, U1.46 (PB9)
/COL6: COL6.1 (1_1), KC_6.1, KC_B1.1, KC_H1.1, KC_SPC1.1, KC_SPC_6.25U1.1, KC_SPLIT_FN_1.25U1.1, KC_Y1.1, U1.45 (PB8)
/COL7: COL7.1 (1_1), KC_7.1, KC_J1.1, KC_N1.1, KC_SPC_2.75U1.1, KC_U1.1, U1.43 (PB7)
/COL8: COL8.1 (1_1), KC_8.1, KC_I1.1, KC_K1.1, KC_M1.1, U1.42 (PB6)
/COL9: COL9.1 (1_1), KC_9.1, KC_COMM1.1, KC_L1.1, KC_O1.1, U1.41 (PB5)
/COL10: COL10.1 (1_1), KC_0.1, KC_DOT1.1, KC_MENU1.1, KC_P1.1, KC_SCLN1.1, U1.40 (PB4)
/COL11: COL11.1 (1_1), KC_LBRC1.1, KC_MINS1.1, KC_QUOT1.1, KC_RALT1.1, KC_RALT_1.25U1.1, KC_SLSH1.1, U1.39 (PB3)
/COL12: COL12.1 (1_1), KC_ENT1.1, KC_ENT_ISO1.1, KC_EQL1.1, KC_RBRC1.1, KC_RGUI1.1, KC_RGUI_1.25U1.1, KC_RSFT1.1, KC_RSFT_2.75u1.1, U1.38 (PA15)
/COL13: COL13.1 (1_1), KC_BKSP1.1, KC_BKSP2.1, KC_BSLS1.1, KC_BSLS2.1, KC_BSLS_ISO1.1, KC_MO1.1, KC_RCTL1.1, KC_RCTL_1.25U1.1, U1.37 (PA14)
/ESD_D+: U1.33 (PA12), U3.4 (I/O2)
/ESD_D-: U1.32 (PA11), U3.6 (I/O1)
/NRST: C9.1, SW2.1, U1.7 (NRST)
/ROW0: D1.1 (K), D2.1 (K), D3.1 (K), D4.1 (K), D5.1 (K), D6.1 (K), D7.1 (K), D8.1 (K), D9.1 (K), D10.1 (K), D11.1 (K), D12.1 (K), D13.1 (K), D14.1 (K), U1.22 (PB11)
/ROW1: D15.1 (K), D16.1 (K), D17.1 (K), D18.1 (K), D19.1 (K), D20.1 (K), D21.1 (K), D22.1 (K), D23.1 (K), D24.1 (K), D25.1 (K), D26.1 (K), D27.1 (K), D28.1 (K), U1.21 (PB10)
/ROW2: D29.1 (K), D30.1 (K), D31.1 (K), D32.1 (K), D33.1 (K), D34.1 (K), D35.1 (K), D36.1 (K), D37.1 (K), D38.1 (K), D39.1 (K), D40.1 (K), D41.1 (K), D42.1 (K), U1.19 (PB1)
/ROW3: D43.1 (K), D44.1 (K), D45.1 (K), D46.1 (K), D47.1 (K), D48.1 (K), D49.1 (K), D50.1 (K), D51.1 (K), D52.1 (K), D53.1 (K), D54.1 (K), D55.1 (K), D69.1 (K), U1.18 (PB0)
/ROW4: D56.1 (K), D57.1 (K), D58.1 (K), D59.1 (K), D60.1 (K), D61.1 (K), D62.1 (K), D70.1 (K), D72.1 (K), D73.1 (K), U1.17 (PA7)
/USB_D+: J1.3, J2.3, J3.3, J4.3, J5.3, J6.3, J7.A6 (D+), J7.B6 (D+), U3.3 (I/O2)
/USB_D-: J1.2, J2.2, J3.2, J4.2, J5.2, J6.2, J7.A7 (D-), J7.B7 (D-), U3.1 (I/O1)
GND: C1.2, C2.2, C3.2, C4.2, C5.2, C6.2, C7.1, C8.1, C9.2, GND1.1 (1_1), J1.4, J2.4, J3.4, J4.4, J5.4, J6.4, J7.A1 (GND), J7.A12 (GND), J7.B1 (GND), J7.B12 (GND), J7.SH (SHIELD), R1.1, R2.2, R3.2, SW2.2, U1.8 (VSSA), U1.23 (VSS), U1.35 (VSS), U1.47 (VSS), U2.1 (GND), U3.2 (GND)
unnamed: D1.2 (A), KC_ESC1.2
unnamed: D2.2 (A), KC_1.2
unnamed: D3.2 (A), KC_2.2
unnamed: D4.2 (A), KC_3.2
unnamed: D5.2 (A), KC_4.2
unnamed: D6.2 (A), KC_5.2
unnamed: D7.2 (A), KC_6.2
unnamed: D8.2 (A), KC_7.2
unnamed: D9.2 (A), KC_8.2
unnamed: D10.2 (A), KC_9.2
unnamed: D11.2 (A), KC_0.2
unnamed: D12.2 (A), KC_MINS1.2
unnamed: D13.2 (A), KC_EQL1.2
unnamed: D14.2 (A), KC_BKSP1.2, KC_BKSP2.2
unnamed: D15.2 (A), KC_TAB1.2
unnamed: D16.2 (A), KC_Q1.2
unnamed: D17.2 (A), KC_W1.2
unnamed: D18.2 (A), KC_E1.2
unnamed: D19.2 (A), KC_R1.2
unnamed: D20.2 (A), KC_T1.2
unnamed: D21.2 (A), KC_Y1.2
unnamed: D22.2 (A), KC_U1.2
unnamed: D23.2 (A), KC_I1.2
unnamed: D24.2 (A), KC_O1.2
unnamed: D25.2 (A), KC_P1.2
unnamed: D26.2 (A), KC_LBRC1.2
unnamed: D27.2 (A), KC_RBRC1.2
unnamed: D28.2 (A), KC_BSLS1.2, KC_BSLS_ISO1.2
unnamed: D29.2 (A), KC_CAPS1.2, KC_STEP1.2
unnamed: D30.2 (A), KC_A1.2
unnamed: D31.2 (A), KC_S1.2
unnamed: D32.2 (A), KC_D1.2
unnamed: D33.2 (A), KC_F1.2
unnamed: D34.2 (A), KC_G1.2
unnamed: D35.2 (A), KC_H1.2
unnamed: D36.2 (A), KC_J1.2
unnamed: D37.2 (A), KC_K1.2
unnamed: D38.2 (A), KC_L1.2
unnamed: D39.2 (A), KC_SCLN1.2
unnamed: D40.2 (A), KC_QUOT1.2
unnamed: D41.2 (A), KC_ENT1.2, KC_ENT_ISO1.2
unnamed: D42.2 (A), KC_BSLS2.2
unnamed: D43.2 (A), KC_LSFT1.2, KC_LSFT2.2
unnamed: D44.2 (A), KC_Z1.2
unnamed: D45.2 (A), KC_X1.2
unnamed: D46.2 (A), KC_C1.2
unnamed: D47.2 (A), KC_V1.2
unnamed: D48.2 (A), KC_B1.2
unnamed: D49.2 (A), KC_N1.2
unnamed: D50.2 (A), KC_M1.2
unnamed: D51.2 (A), KC_COMM1.2
unnamed: D52.2 (A), KC_DOT1.2
unnamed: D53.2 (A), KC_SLSH1.2
unnamed: D54.2 (A), KC_RSFT1.2, KC_RSFT_2.75u1.2
unnamed: D55.2 (A), KC_MO1.2
unnamed: D56.2 (A), KC_LCTL1.2, KC_LCTL_1.25U1.2
unnamed: D57.2 (A), KC_LGUI1.2, KC_LGUI_1.25U1.2
unnamed: D58.2 (A), KC_LALT1.2, KC_LALT_1.25U1.2
unnamed: D59.2 (A), KC_SPC1.2, KC_SPC_6.25U1.2, KC_SPLIT_FN_1.25U1.2
unnamed: D60.2 (A), KC_RALT1.2, KC_RALT_1.25U1.2
unnamed: D61.2 (A), KC_RGUI1.2, KC_RGUI_1.25U1.2
unnamed: D62.2 (A), KC_RCTL1.2, KC_RCTL_1.25U1.2
unnamed: D69.2 (A), KC_<>1.2
unnamed: D70.2 (A), KC_SPLIT_SPC_2.25U1.2
unnamed: D72.2 (A), KC_MENU1.2
unnamed: D73.2 (A), KC_SPC_2.75U1.2
unnamed: J7.A5 (CC1), R2.1
unnamed: J7.B5 (CC2), R3.1

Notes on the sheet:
Reset Button
Microcontroller
Voltage Regulator
Extra Diodes
JST-SH 4 Pin Connector
Bootloader Button
On-Board USB-C Connector
ESD Protection
Decoupling Capacitors
Switch Matrix

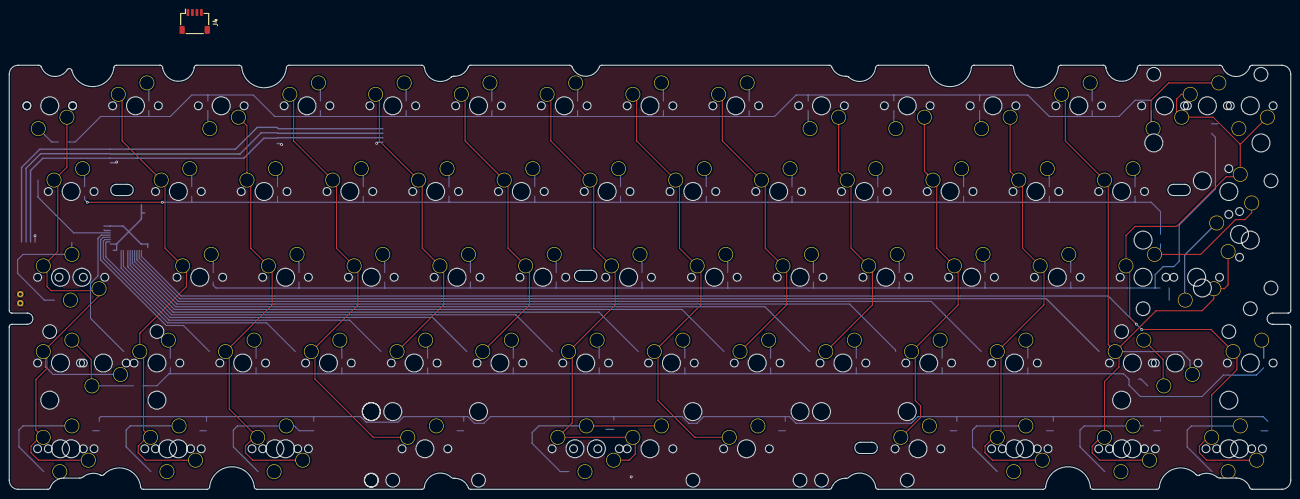
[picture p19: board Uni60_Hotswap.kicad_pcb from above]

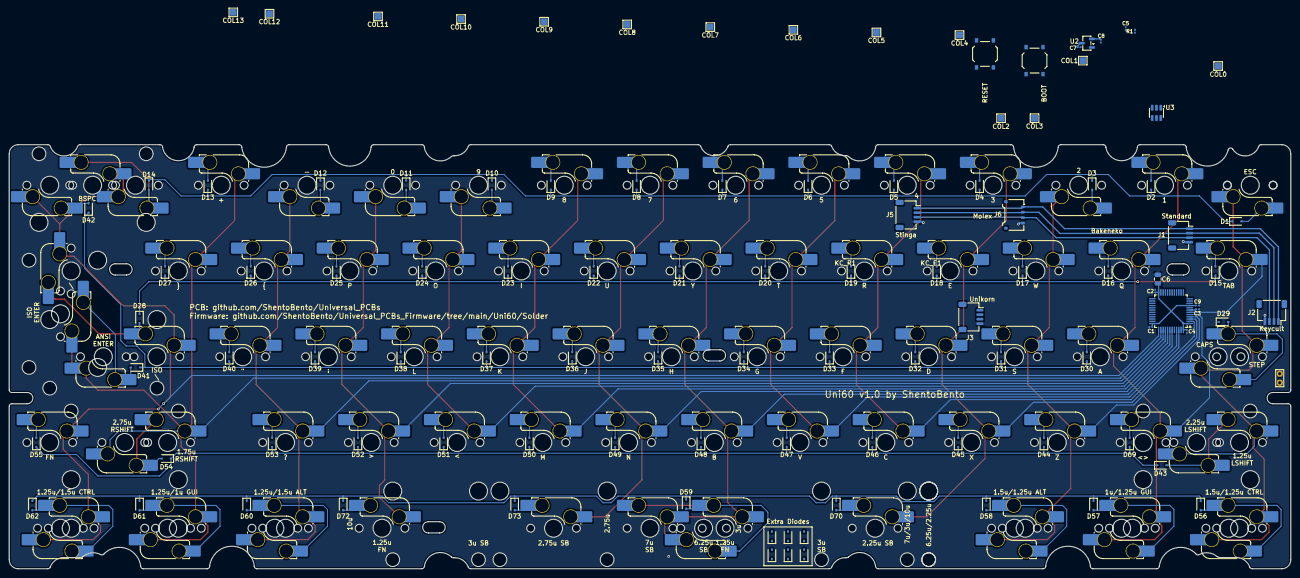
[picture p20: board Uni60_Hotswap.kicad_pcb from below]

Board: 2 copper layers, 284.7 x 94.2 mm, 188 parts (187 on the bottom side), 94 nets.

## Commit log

2026-07-30 UNI60 Solder added
    [HS_CPG151101S11_MX.step, HS_KS-2P02B01-01_MX.step, LED_MHT151RGBCT.step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]
2026-07-30 aadded full 2.75u rshift support
    [Uni60_Solder.kicad_pcb, Uni60_Solder.kicad_sch]
2026-07-30 moved jst to venom60he jst position
    [JST Position.DXF, Uni60_Solder.kicad_pcb]
2026-08-05 idk what changed tbh
    [Uni60_Solder.kicad_pcb, Uni60_Solder.kicad_sch]
2026-08-25 added stinga support
    [UNI60_PCB_OUTLINE.SLDPRT, Uni60_PCB_Outline_v3.DXF, Uni60_Solder.kicad_pcb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]
2026-08-25 updated traces
    [Uni60_Solder.kicad_pcb]
2026-08-25 added molex connector to my library
    [UNI60_PCB.SLDASM, UNI60_PCB.step, Uni60_Solder.kicad_pcb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]
2026-08-26 changed hole ID sizes to 1.55mm
    [Uni60_Solder.kicad_pcb, Uni60_Solder.kicad_sch]
2026-08-26 fixing minor trace errors
    [Uni60_Solder.kicad_pcb]
2026-08-26 minor trace errors
    [Uni60_Solder.kicad_pcb]
2026-08-26 added new files, removed old files
    [UNI60_PCB.SLDASM, UNI60_PCB.step, UNI60_PCB_OUTLINE.SLDPRT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]
2026-08-26 Update README for Uni60 Solder PCB
2026-08-26 Add socket diameter details to README
    Added socket diameter information for compatibility.
2026-08-27 fixed traces
    [Uni60_Solder.kicad_pcb, Uni60_Solder.kicad_sch]
2026-08-27 moved images to images folder
    [Uni60_Hotswap.kicad_pcb, Uni60_Hotswap.kicad_sch]
2026-08-27 started hotswap uni60
    [Uni60_Hotswap.kicad_pcb, Uni60_Hotswap.kicad_sch]
2026-08-27 changed solder to hotswap sockets
    [Uni60_Hotswap.kicad_pcb, Uni60_Hotswap.kicad_sch]
2026-08-27 wiring up sockets
    [Uni60_Hotswap.kicad_pcb]
2026-09-01 final changes
    [Uni60_Hotswap.kicad_pcb, Uni60_Solder.kicad_pcb, bom.csv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]
2026-09-06 added alps footprints
    [Uni60_Solder.kicad_pcb]
2026-09-08 added alps-mx footprints
    [Uni60_Solder.kicad_pcb, Uni60_Solder.kicad_sch]
2026-09-09 wired up columns
    [Uni60_Hotswap.kicad_pcb, Uni60_Hotswap.kicad_sch]
2026-09-16 minor trace adjustments
    [Uni60_Hotswap.kicad_pcb]
2026-10-04 Add root README describing the Universal PCBs collection
